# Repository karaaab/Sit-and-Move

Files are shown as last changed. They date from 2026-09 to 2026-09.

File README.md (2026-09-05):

## About the Sit-and-Move

The Sit-and-Move is a motorized wheelchair module for young children ages 1-6, created by a group of students in the TU Make a Difference Engineering class, in conjunction with the Little Light House. It is loosely based on the "Sit-n-Moove" project from 2017, which was a motorized (non modular) wheelchair for the same organization.

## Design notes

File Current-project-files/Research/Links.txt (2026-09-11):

https://www.quantumrehab.com/resources/consumer-article-how-fast-do-motorized-wheelchairs-go.as
Seeed XIAO Microcontroller board: https://www.seeedstudio.com/XIAO-ESP32S3-p-5627.html

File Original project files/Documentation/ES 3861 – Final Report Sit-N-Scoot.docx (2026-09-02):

ES 3861 – MADE at TU (Make a Difference Engineering)

Project Final Report

Due date: Friday, December 2, 2016

Project Final Report: Each MADE at TU team* must submit a final report describing its accomplishments this semester. Please fill in the missing information in this document, rename the file, and email it back to Dr. Henshaw and to David Wright. Please use the subject line, “MADE Final Report spring 2016.” Please also print the document and turn it in in class on the due date.

*One report per team (not per student)

Project and team

Name of project: Motorized Sit-n-Scoot Team leader: Duy Van

Team members*

1. Duy Van

2. Osamh Hasreem

3. Melida Perez-Errasquin

4.

5.

6.

7.

When did MADE at TU first begin working on this project? (Semester and year)

Fall 2015

Customers

Who are the customers for your project? (include both the institution, for example, “the Little Light House school,” and the type of persons who will use your project, for example, “children with cortical blindness and other vision problems.”)

We have been working closely with the Little Light House, developing a wheel chair for children who have troubles with normal wheel chair. This is due to several reasons:

- Child is too small for wheelchair
- The child has had accidents on wheelchair and the material makes it hard to clean up
- Child cannot reach wheelchair wheels
- Wheelchair is too high off the ground to interact with other kids
- Child is too weak for the full weight of a heavy duty wheelchair

Project goals

Summarize your project’s overall goals

The goal of this project is to continue development from the previously delivered Sit-N-Scoot. We wanted to create a working and safe motorized version for kids who are not able to use their hands for mobility.

Progress this semester

What has your team accomplished this semester? Describe any design, analysis, fabrication, or other work that was done. Include photos, drawings, etc., as appropriate. This is the most important section of your report.

This semester we finished the whole mechanical system. With the help of north campus, we were able to attach the motor and stepper motor to the first prototype wheelchair. We did this by adding connections from the top block to the back of the wheelchair and mounted it with bolts and nuts. (Attachment #1) We tested the motor along with the driver that we bought with some sample code and they both work. We can now run the Sit-N-Scoot forwards, backwards, and rotate it a potential meter on a breadboard. To assure that the motor had enough power, we tested the motorized sit-n-scoot with a sample code at the Little Light House. The Sit-N-Scoot was about to work well on the wood floor, the carper, over the edges between two surfaces and up the wheel chair ramps they have.

Expected delivery date

When do you expect that your prototype hardware will be delivered to your customer?

We expect to be able to get a mobile Sit-N-Scoot to the Little Light House within the first month of the next semester. However, we expect to have to come back and modify a couple of things they might need us to, and therefore think it will be half way into next the Spring 2017 semester before we have a fully working Sit-N-Scoot at the Little Light House.

Future work

Make a list (1., 2., 3., etc.) of the steps that need to be accomplished in the next semester(s), leading up to the delivery of your project. Be as specific as you can! Please avoid vague answers such as, “1. Finish building project,” “2. Test project.” Your grade on this section will be based on how specific and detailed your answers are.

1) Finnish the coding (with helps from David, Dr. Daily and friends)
2) Test the coding to make sure that it matches the commands from the joystick
3) Assemble all the wiring and battery onto the chair
4) Build a housing unit on the Sit-N-Scoot to shelter the battery and the wires components
5) Design a cover over the driving mechanism for safety
6) Deliver the Sit-N-Scoot to the Little Light House for testing
7) Fix any possible problems the Little Light House finds
8) Repeat steps 6&7 until there are no problems. The Sit-N-Scoot is now ready to be left permanently at the Little Light House

Budget

Estimate the total amount of money spent on your project this semester.

Item | Estimated cost
1. Coupling | $13.99
2. 12V Battery Charger | $21.89
3. Stepper Motor Driver | $16.90
4.
5.
6.
Semester total | $52.78

Obtained an extra $180 Research Grant for this semester

Attachment #1

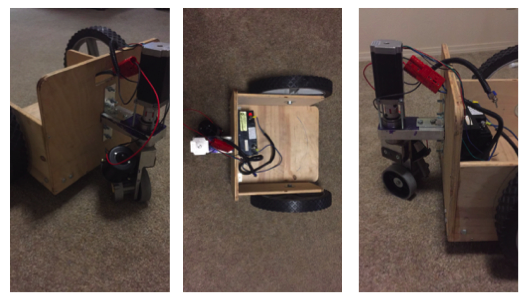
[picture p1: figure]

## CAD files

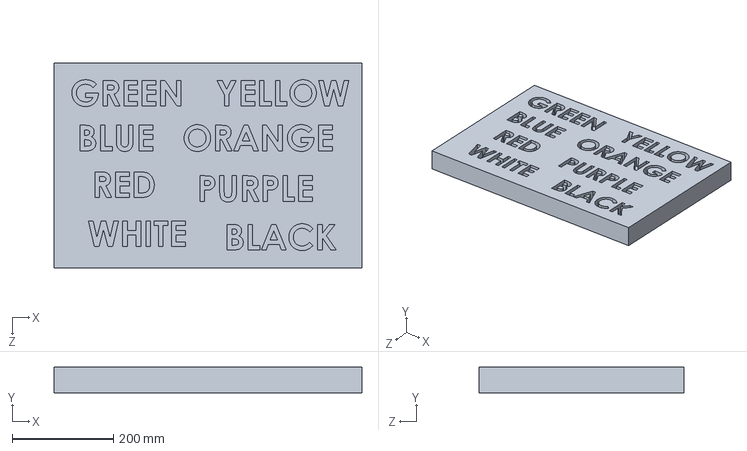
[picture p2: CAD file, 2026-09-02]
Original project files/3D Models/Puzzle Project.SLDPRT
609.6 x 50.8 x 406.4 mm

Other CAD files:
Original project files/3D Models/Bottom Part.SLDPRT
Original project files/3D Models/Base Flower.SLDPRT
Original project files/3D Models/Arduino top case.SLDPRT
Original project files/3D Models/Arduino Bottom case.SLDPRT
Original project files/3D Models/Black Box Trial 2.SLDPRT
Original project files/3D Models/Flower top.SLDPRT
Original project files/3D Models/Black Box.SLDPRT
Original project files/3D Models/Arduino top case.DXF
Original project files/3D Models/Base Flower.DXF
Original project files/3D Models/Black Box Trial 2.DXF
Original project files/3D Models/Bottom Part.DXF
Original project files/3D Models/Flower top.DXF

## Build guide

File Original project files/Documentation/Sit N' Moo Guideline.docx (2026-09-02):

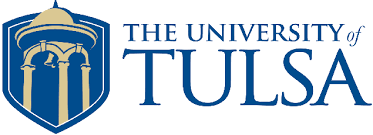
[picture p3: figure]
Image result for Tulsa logo
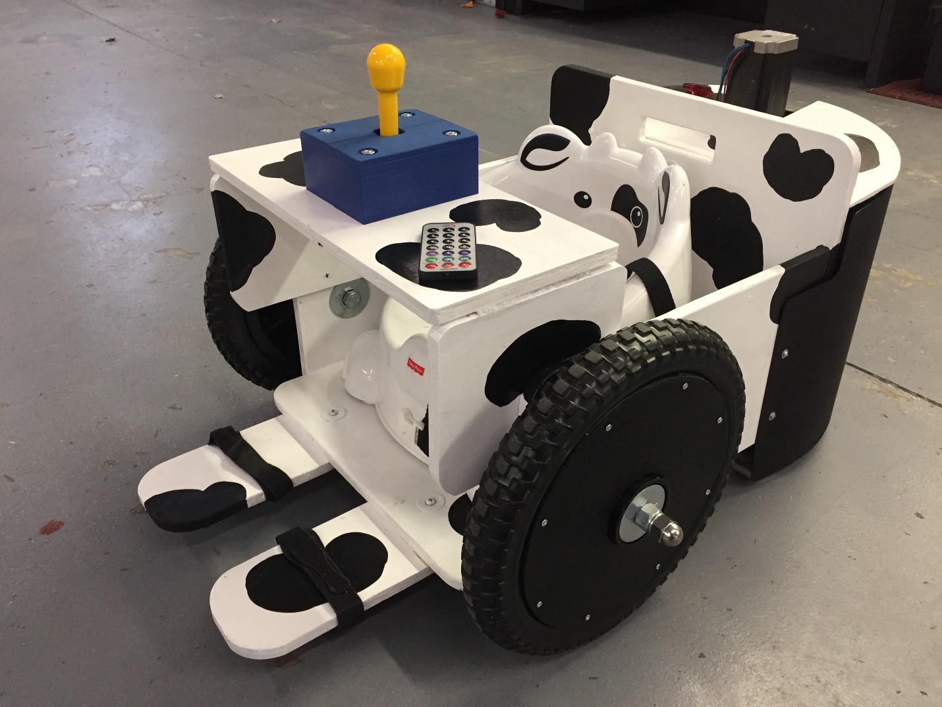
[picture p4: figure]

Sit N’ Moo(ve)

Guideline

I. Device operation
- Please check if the steering motor is in range (not all the way to the right). The motor may move out of the right limit switch if the device is picked up sideway
- To turn on the device, open the red cover on the switch and push it to the on position (all the way because the switch has three positions)
- To go forward, push joystick forward
  - To turn left while going forward, push the joystick to the left while pushing the joystick forward
  - To turn right while going forward, push the joystick to the right while pushing the joystick forward
- To go backward, push joystick backward
  - To turn left while going backward, push the joystick to the left while pushing the joystick backward
  - To turn right while going backward, push the joystick to the right while pushing the joystick backward
- Push joystick to the left or right only will have no effect
- To turn off the device, close the switch cover
- The battery will last about an hour with continuous use. The obvious sign of low battery will be that the device will have no power moving backward
II. Charging
- Open the top cover, unplug the red and black wires connected to the battery terminals, attach the red and black charging cable to the red and black terminal on the battery, respectively
- Plug in the charger with 12V option (not 6V)
- Please be careful not to move any other wires
III. Emergency shutoff switch
- To turn off the device for emergency, close the switch cover
IV. Remote shutoff
- To remotely shutoff the device that is operating, aim the remote directly to the back of the device and press one of the red buttons on the first row. You may have to adjust your position properly to get it right. The red LED will turn on indicating that the device is temporarily disable
- To get back normal operation, aim the remote directly to the back of the device and press one of the green buttons on the second row
V. Troubleshooting
- If the device is not working properly such as making weird jerking sound when trying to turn or need a repair. This could be due to wiring problem, please do not attempt to fix it yourself
- Please contact Dr. Henshaw at The University of Tulsa for repair
VI. Contact

John Henshaw – 918 631 3002

John-henshaw@utulsa.edu

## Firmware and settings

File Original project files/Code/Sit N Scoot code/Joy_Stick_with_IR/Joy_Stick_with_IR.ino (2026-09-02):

/* Include the library */
#include <HCMotor.h>
#include <IRremote.h>
#include <elapsedMillis.h>

//Define variables
int x = 0;
int y = 0;
int dir;
int Speed;


int RPWM_Output = 5; // Arduino PWM output pin 5; connect to IBT-2 pin 1 (RPWM)
int LPWM_Output = 6; // Arduino PWM output pin 6; connect to IBT-2 pin 2 (LPWM)

/* Pins used for Stepper Motor */
#define DIR_PIN 8 //Connect to drive modules 'direction' input.
#define CLK_PIN 9 //Connect to drive modules 'step' or 'CLK' input.

//Set up timing variables
#define speed_adjust_t 4
#define speed_slow_t 2

elapsedMillis forward_time;
elapsedMillis backward_time;
elapsedMillis neutral_time;
elapsedMillis print_time;


const int buttonPinRight = 3; 
int buttonStateRight = 0;

const int buttonPinLeft = 4; 
int buttonStateLeft = 0;

const int buttonPinF = 10; /*pink wire*/
int buttonStateF = 0;

const int buttonPinB = 11; /*yellow wire*/
int buttonStateB = 0;

const int buttonPinL = 12; /*orange wire*/
int buttonStateL = 0;

const int buttonPinR = 7; /*green wire*/
int buttonStateR = 0;

//Set IR remote pin and LED pin
int RECV_PIN = 2;
int LED = 13;

//Set machine state for remote switch
bool machine = true;

//IR remote code
long off1  = 0x00FFA25D;
long on1 = 0x00FF22DD;
long off2 = 0x00FF629D;
long on2 = 0x00FF02FD;
long off3 = 0x00FFE21D;
long on3 = 0x00FFC23D;

IRrecv irrecv(RECV_PIN);
decode_results results;

HCMotor HCMotor;

void setup()
{
  pinMode(RECV_PIN, INPUT);
  pinMode(LED, OUTPUT);
  Serial.begin(9600);
  pinMode(RPWM_Output, OUTPUT);
  pinMode(LPWM_Output, OUTPUT);
  
  /* Initialise the library */
  HCMotor.Init();
 
  /* Attach motor 0 to digital pins 8 & 9. The first parameter specifies the 
     motor number, the second is the motor type, and the third and forth are the 
     digital pins that will control the motor */
  HCMotor.attach(0, STEPPER, CLK_PIN, DIR_PIN);
 
  /* Set the number of steps to continuous so the the motor is always turning whilst 
     not int he dead zone*/
  HCMotor.Steps(0,CONTINUOUS);

  pinMode (buttonPinLeft,INPUT);
  pinMode (buttonPinRight,INPUT);
  pinMode (buttonPinF,INPUT);
  pinMode (buttonPinL,INPUT);
  pinMode (buttonPinR,INPUT);
  pinMode (buttonPinB,INPUT);

  irrecv.enableIRIn();

}
 
void loop()
{   
  //Condition for remote shutoff switch
  if (irrecv.decode(&results)) 
   {
    
    if (results.value == on1 or results.value == on2 or results.value == on3 ){
      machine = true;
    }
    else if (results.value == off1 or results.value == off2 or results.value == off3 ){
      machine = false;
    }     
    irrecv.resume(); // Receive the next value
  }

//If machine is enable, run
if (machine == true)
  {digitalWrite(LED,LOW);
  buttonStateLeft = digitalRead(buttonPinLeft);
  buttonStateRight = digitalRead(buttonPinRight);
  buttonStateF = digitalRead(buttonPinF);
  buttonStateB = digitalRead(buttonPinB);
  buttonStateL = digitalRead(buttonPinL);
  buttonStateR = digitalRead(buttonPinR);
  
  //Foward, speed of drive motor is controlled between 0 to 255
  if (buttonStateF == HIGH){
    dir = 1;
    if (forward_time > speed_adjust_t){
      forward_time = 0;
      
      x++;
      if (x>255){
        x = 255;
      }
    }
  }

  //Backward
  if (buttonStateB == HIGH){
    dir = 0;
    if (backward_time > speed_adjust_t){
      backward_time = 0;
      
      y++;
      if (y>255){
        y = 255;
      }
    }
  }

  //Neutral state
  if (buttonStateF == LOW and buttonStateB == LOW){
    if (neutral_time > speed_slow_t){
      neutral_time = 0;
      x= x-2;
      y= y -2;
      if (x <0){
        x = 0;
      }
      if (y<0){
        y = 0;
      }
      }
  }

  //Make sure the device is not running before switch direction
  if (x != 0 and buttonStateB ==HIGH){
    dir = 1;
    if (backward_time > speed_slow_t){
      backward_time = 0;
      x--;
      if (x<0){
        x=0;
      }
    }
  }

   if (y != 0 and buttonStateF ==HIGH){
    dir = 0;
    if (forward_time > speed_slow_t){
      forward_time = 0;
      y--;
      if (y<0){
        y=0;
      }
    }
  }

  //Direction to go forward
  if (dir == 1){
    analogWrite(RPWM_Output,x); 
  }

  //Direction to go backward
  if (dir == 0){
    analogWrite(LPWM_Output,y);
  }

  //Steering Left
    if (buttonStateL == HIGH)
  {
    HCMotor.Direction(0,FORWARD);
    Speed = 20; // The smaller the speed, the faster the stepper motor steers
  }
  
  //Steering Right
  else if (buttonStateR == HIGH)
  {
    HCMotor.Direction(0,REVERSE);
    Speed = 20;
  }

  //Steering neutral
  else if (buttonStateR == LOW and buttonStateL == LOW)
  {
    Speed = 0;
    
  }

  //This is for steering back to neutral position
  if (buttonStateL == HIGH && buttonStateLeft == HIGH)
  { HCMotor.Direction(0,FORWARD);
    Speed = 0;}
  if (buttonStateL == LOW && buttonStateLeft == HIGH)
  { HCMotor.Direction(0,REVERSE);
    Speed = 10;
    delay(280);
  }
    
   if (buttonStateR == HIGH && buttonStateRight == HIGH)
  { HCMotor.Direction(0,REVERSE);
    Speed = 0;
  }
  if (buttonStateR == LOW && buttonStateRight == HIGH)
  { HCMotor.Direction(0,FORWARD);
    Speed = 10;
    delay(250);
  }
HCMotor.DutyCycle(0, Speed);
}

//If machine is disable, turn LED on and do nothing
if (machine == false){
  digitalWrite(LED,HIGH);
  analogWrite(RPWM_Output,0);
  analogWrite(LPWM_Output,0);
  HCMotor.DutyCycle(0, 0);
  x=0;
  y=0;
}
}

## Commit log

2026-09-02 added 2017 original project files for reference
    [Arduino Bottom case.SLDPRT, Arduino top case.DXF, Arduino top case.SLDPRT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]
2026-09-04 Created models subdirectory
    For CAD, electrical drawings, etc.
2026-10-04 Sit N Move Schematic
    1st draft of the schematics
    [SitNMove_schematic.kicad_pcb, SitNMove_schematic.kicad_sch]
2026-11-06 added voltage reg datasheet
2026-11-06 corrected voltage regulator datasheet
2026-11-06 added FET datasheet
2026-11-13 Add Transistor Wiring Diagram
    Model of test prototype to test the model's motor switching capabilities.
2026-11-13 added sprocket file
2026-11-13 ESP32C3 Guide
